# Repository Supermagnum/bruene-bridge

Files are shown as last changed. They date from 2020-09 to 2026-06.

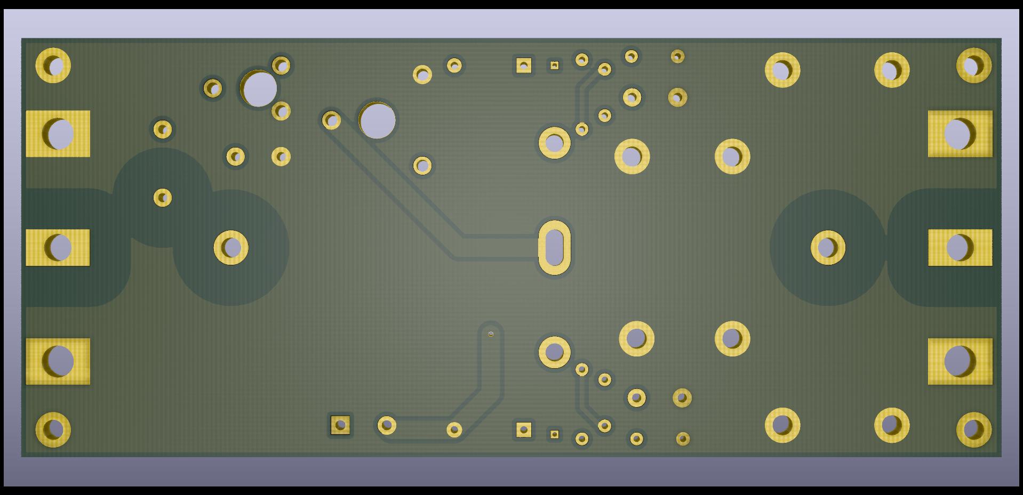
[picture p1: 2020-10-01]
SWR bridge-rendering-backside.jpg

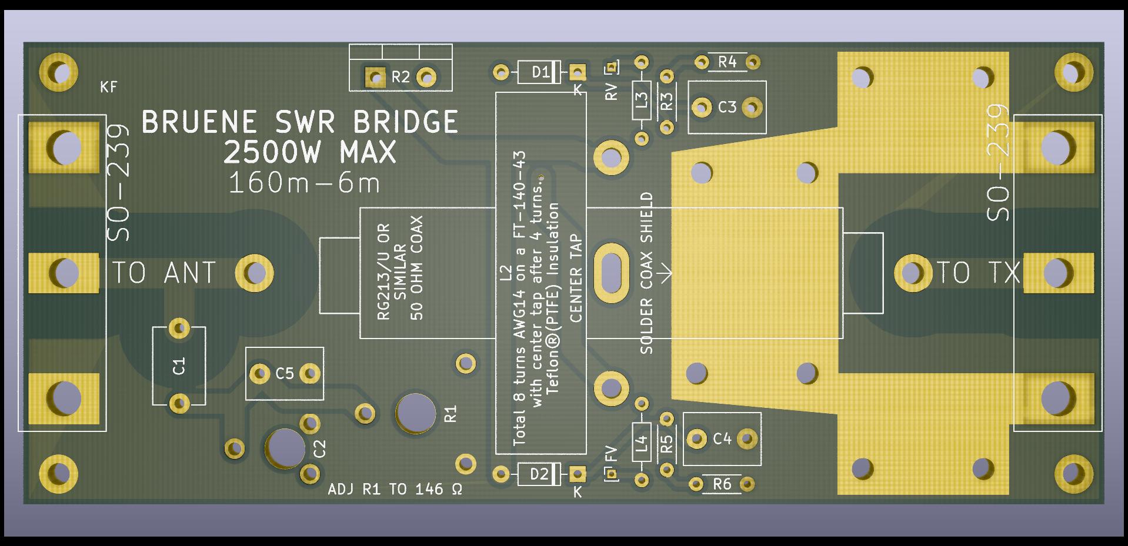
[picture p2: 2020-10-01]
SWR bridge-rendering.jpg

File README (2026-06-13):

SWR AND POWER MODIFIED BRUENE BRIDGE.

Circuit originally designed by F1FRV . 
This design is applicable for small or high powers, from 100 kHz (or less) to 50 Mhz, from miliwatts to kilowatts, depending on the selected components. For best results, for WIDEBAND use the ferrite "43" material. Materials "4C6 or 4C65" generaly painted in purple, are identical to material "61" and can also be used (with much more turns than "43" for same inductance).

With good electrical and mechanical design, using parts described here, and PCB designed for, 1.8 to 30 (50) MHz directivity can be better than 35 dB, and accuracy in power measurements in the range 1 to 2 %. 

Generaly, if it dont works, it is with people more clever, and better technicians than me, who dont want to follow EXACTLY what is written, and do what they feel instead.

Coaxial line shield must be grounded ONLY 1 side of toroid, 1 time at input connector, and 1 time just near toroid. Place the WIDE ground return strip(s), not a single wire, between coaxial line, circuit board and main ground frame, as close as possible to the toroid, to have the best accuracy in POWER measurements over a wide range of frequencies. For SWR measurements ONLY, this is not very important, as the ratio FWD/REF is independant of absolute values of detected voltages.To avoid parasitic capacitances, place the PCB at least 10 mm above metallic enclosures.

To have perfect balance of the bridge, with the calculated values given by EXCEL sheet, it is important to know the " TRUE " values of the coil(s), resistor R2, and capacitor C1. To know what is the exact Al value of your toroid, coil 5 turns of wire into it, measure with a LC meter, and divide value by 25. With an Ohmmeter, adjust VR1 to the value given by excel sheet.The variable C2 capacitor, as shown, is MANDATORY, to compensate for all tolerances in components values, parasitics. During tests, dont hesitate to modify calculated value of C2 (fixed + adjustable value) to obtain the best balance.Tolerances and parasitic capacitances management are unfortunately not exact sciences. Adjustment of phase compensation C2 must be made, ONLY at bridge maximum frequency of use. If null is not OK with C2, readjust slightly VR1 and C2, at max frequency of use, to obtain perfect null. Reverse bridge in /out to check null symetry.

Check of coil(s) and capacitor C1 exact values can be made with a LC meter, like the one described in pages " Technical " and proposed by DF1SR (ex DD0SB).

Adapt cross sectional area of wires in toroid to maximum current in R2, do not undersize, 3 Amps by square milimeter is a maximum.

Load on detector diodes is a first order parametre for rectified voltages output. Do not hesitate to use operational amplifiers LM358 or LM324 as buffers (they include GND in common mode range). In this case, with very high impedance detectors load, to avoid too high time constant in SWR readings, reduce, if necessary, the values of decoupling capacitors (ceramic) in FWD & REF outputs. 2.2 to 10 nF is OK with operational amplifiers, 100 nF or more without operational amplifiers.

Source for text : F1FRV 's page :
http://f1frv.free.fr/main3h_SWR_Bridges.html

What I have done:
Made a PCB that uses more modern components , as a example is C2 variable cap.
That one is impossible to use for a PCB design because the factory drawings is completely unreadable!
So, I have made adjustments with a smaller adjustable one that goes from 5.5-65pF in paralell with a 100 pF one. So the range of adjustment is 105 to 165 pF.

C1 is a 1pF ±0.5pF 4000V (4kV) Ceramic disc capacitator, clouse enough to the calulated 0,96 pF

I have added solder connectors to SO-239 connectors, 
they will fit if they are soldered in a 45 degree angle as then two of the mounting screws and the center pin can be soldered directly to the board.
It includes voltage dividers so the rectified forward and reverse voltages is suitable for a Aurdinos ADC ports ( 5v DC max ). 
The traces that carries RF is 3mm wide, and short.
It also includes a big area for soldering the coax cable shield to, 
and a copper strap can also be used to squeeze the coax cable shield between the strap and PCB.
It is also possible to mount grounding straps to the PCB. 

R2 is a 30W Through Hole Resistor TO-220-2, in a suitable location for mounting to the sheilded box wall or a heat sink. 

The PFD file contains calculations for up to 2500 W, more than enough because the legal limit in many places is 1000 W.
https://github.com/Supermagnum/bruene-bridge/blob/master/SWR-bridge.pdf

All components is THT.

PCB's:
https://aisler.net/p/KSGINYGY

PCB picture:
https://github.com/Supermagnum/bruene-bridge/blob/master/SWR%20bridge-rendering.jpg

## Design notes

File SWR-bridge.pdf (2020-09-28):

Revision 2 02/07/2004
Included in rectified voltage calculations the fact that:
Diode detection law below threshold voltage is linear
Diode detection law over threshold voltage is quadratic
Minimum detected power is taken as 0,5% of meter full scale
L1/R2 ratio at minimum frequecy decreased from >8 to ~5 to improve accuracy at high side of the useful band

Revision 3 17/07/2004
Included software MINIRK.EXE in spreadsheet Improved DC rectified voltages calculations lines 25 & 26

Revision 4 25/07/2004
Added wattmeter full scale value
Modified minimum detected power calculation

Revision 5 January 2006
Added schottky diode max voltage
and check of value in fwd & ref voltages. Becomes black on red if value too high

Revision 6 July 15, 2006
Check of value of diode maximum reverse peak voltage (Vr). Becomes black on red if value too low Diode Vr max shall be less than Vrms x ~4
Removed check in fwd & ref dc voltages

Revision 6a July 17, 2006
Added test measurements results table & graph Page now in "landscape"
Added calculations for R1 with 2 paralleded resistors

Revision 7a November 11, 2006
Added information about GND strap

Revision 7b April 21, 2007
Added Check flux with MINIRK12 to avoid toroid saturation at lowest frequency If toroid is saturated, increase size or redduce voltage

Revision 8 September 09, 2008
Modified bridge drawing to have phase compensation antenna side Added maximum flux in toroid verification sheet
Added selection list for toroids and automatic Al choice
Added AMIDON material 43 and 61 toroids data

Revision 8a September 10, 2008
Added material "2" in calculations and documentation

Revision 8b September 19, 2008
Included coupling factor 99% for L1
added nota about ratio L1/R2 and accuracy

Revision 8c September 30, 2008
added warning colors for ratio L1/R2 less than 7 and 5

Revision 8d November 06, 2008
Modified safety ratio warning for detectors PIV. Is now 2.88 x RMS voltage

Revision 8e November 23, 2010
Correction of not very clear texts: in C1 manual calculation
and in R2 dissipated power

Revision 9 November 25, 2010
Added TRUE MEASURED value of toroid AL

Revision 10 December 07, 2010
Added minimum supply voltage of automatic SWR board

Revision 10a March 30, 2011
Added nota about TRUE measured AL

Revision 10b April 21, 2011
Corrected data source in results graph which was not working

Revision 10c February 1st, 2012
Added nota line 30, to decrease output voltages if necessary.

Revision 10d August 15, 2012

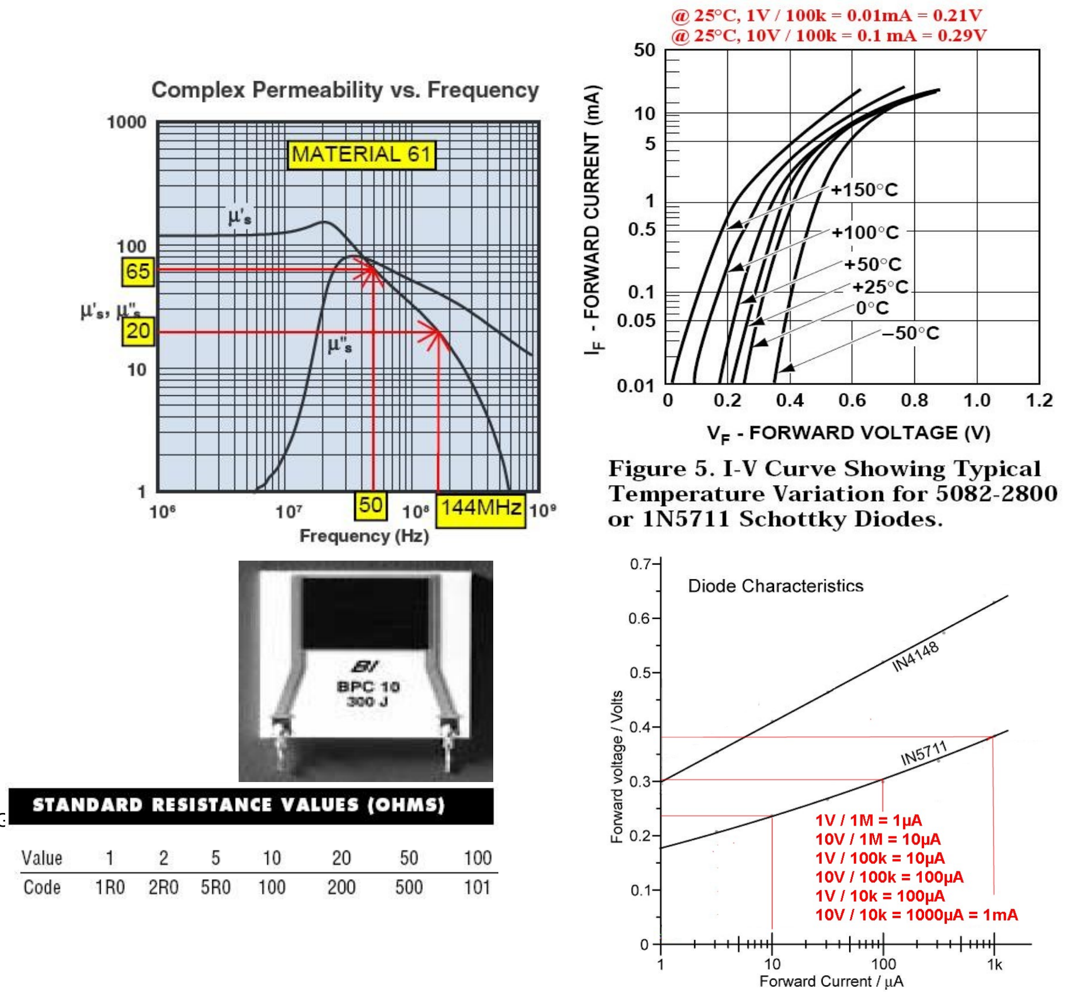
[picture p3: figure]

Deleted the material 2, red toroids, as NOT ADAPTED TO WIDEBAND DESIGNS

Revision 11 January 07, 2014
Modified Cell C18: C2 (pF) adjustable (+ fixed value if necessary)
Formula was: =(2*2^0.5*C8*C16*C3)/C12-C16
Formula now: =(2*C8*C16*C3)/C12-C16
Replaced R1 by variable resistor VR1

NOTA: For monoband 50 MHz with material 61, divide NOMINAL Al of toroid by 2 NOTA: For monoband 144 MHz with material 61, divide NOMINAL Al of toroid by 6

Revision 12 December 11, 2014
Modified Cell C7: Becomes "True AL" if true AL entered in cell F7
Added nota about max nb of turns.
R2 BPC10 (10 Watts) serie standard values see picture
Added wire CSA calculation
Added notas lines 31 to 33

Revision 13 January 2020
Modified formula in cells C26 & C27 which was: =SI(C20>C25;((C25+(C20-C25)*PI()/2));C20)

F1FRV January 2020 REVISION 13 | MEASUREMENT RESULTS WITH POWER 40 WATTS / 50 OHMS WITH
VOLTMETER 10 MEGOHMS/V
LINE IMPEDANCE Z (Ohms) | 50 | | | | FREQUENCY (MHz) | FWD VALUE | | REF VALUE
Maximum power (Watts) | | | | | 1,8 | 690 | mV | 0,10 | mV | FT 50-43
| 10,0 | | | | 3,5 | 693 | mV | 0,10 | mV | FT 82-43
Reference of toroid | FT 140-43 | >> | | | 5,0 | 694 | mV | 0,10 | mV | FT 114-43
| 885,0 | >> | | | 7,0 | 695 | mV | 0,10 | mV | FT 140-43
| 8 | | | | 10,0 | 689 | mV | 0,10 | mV | FT 240-43
L1 (uH) with coupling factor 0.99 | 56,074 | If Total Nb of turns > 10, Decrease R2 value. | 14,0 | 680 | mV | 0,10 | mV | FT 50-61
Bridge Minimum Frequency of use (MHz) | 1,800 | This, to minimize L1 parasitic capacitances. | 18,0 | 678 | mV | 0,10 | mV | FT 82-61
126,8 | >> L1/R2 = 3 power error ~5% and phase ~18° | 21,0 | 679 | mV | 0,10 | mV | FT 114-61
R2 (Ohms) Shall be NON INDUCTIVE !!! | 5,00 | L1/R2 = 7 power error ~1% and phase ~8° | 24,9 | 680 | mV | 0,10 | mV | FT 140-61
Max current in R2 and toroid winding (Amps) | 3,95 | >> Wire MIN CSA (sq mm) | 1,32 | 28,0 | 689 | mV | 0,10 | mV | FT 240-61
Bridge coupling design dB | 47,09 | | Wire MIN Dia. (mm) | 1,30 | 30,0 | 682 | mV | 0,10 | mV | ??
R2 dissipated power (Watts) at maximum permanent power | 7,81 | >> | AT MAXIMUM SWR : | 10,00 | 50,0 | 683 | mV | 0,10 | mV | ??
C1 (pF) | 0,96 | >> | 2 x RG 402 | pF/m | MEAN VALUE | 686 | mV | 0,10 | mV | ??
Max Voltage on C1 (Volts peak/peak) | | | 2 x 2000 V MAX | 95,1 | MAXIMUM ERROR +/- | 1,8 | % | | | ??
C2 (pF) adjustable (+ C2a fixed value if necessary) | 152,6 | C1 MANUAL CALCULATION | BRIDGE DIRECTIVITY | 38,4 | dB | ??
VR1 variable resistor to adjust with Ohmmeter at value | | | 2 lengths of (mm) | 20,0
FWD Volts on R2 (Volts rms) | 5,44 | | C1 (pF) incl. strays | 0,96
REF Voltage on R2 (Volts rms) | 4,45 | See Picture at page bottom
FWD Apparent Power (Watts)
REF Apparent Power (Watts)
Detection diode maximum Peak Inverse Voltage (Volts) | 70 | >> | See diode manufacturer data for values.
Detection diode Treshold Forward Voltage (Volts) | 0,180 | >> | Quadratic detection below threshold voltage
Estimated forward rectified voltage (DC Volts) | 7,611 | Linear detection over threshold voltage (FV).
Estimated reflected rectified voltage (DC Volts) | 6,213
With output power (Watts) | | | Auto SWR supply V > 9,7
Minimum reflected detected power will be (Watts) | 0,364 | >> with directivity measured in tests
Nota: If necessary, install a resistive divider to reduce FWD & REF voltages outputs, for auto SWR lower supply voltage. To estimate maximum output voltages & currents, modify max SWR (cell B5)
IMPORTANT: C2 adjustment mus be made ONLY at bridge maximum frequency of service.

COLOR CODE: INPUTS= BLUE / OUTPUTS= RED / INFORMATION= BLACK
( See revisions page ) | ENTER YOUR MEASURED VALUES !!

2 500
PERMANENT Maximum SWR to be accepted by the bridge CLICK HERE FOR TOROID FLUX VERIFICATION PAGE !! Nominal average AL of toroid (nH / turn²
) | True measured AL :
Nb TOTAL of turns (N) INSIDE toroid (2 x N/2) ( MUST be EVEN !! ) | True measured AL MUST stay BLANK if no measured AL

L1 / R2 ratio at minimum freq. (shall be >7 for <1% accuracy )

1 581

146 025

7 562,50
5 062,50 | 1N4148 (PIV 100V, FV 0.3V @ 1uA) High FV.

1N5711 (PIV 70V, FV 0.18V @ 1uA) is the best. 2 500

Nota: Coaxial line must be grounded ONLY 1 SIDE OF TOROID, 1 x just behind toroid, AND 1 x at TX connector.

1,8
3,5

5,0

7,0
10,0
14,0

18,0

21,0

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
1000

### FWD DETECTION (mV) @ FREQUENCY (MHz)

TOROIDS FLUX CALCULATIONS | CALCUL DU FLUX DANS LES TORES | F1FRV January 2020 REVISION 13
Results: Red on yellow | Résultats: Rouge sur fond jaune

IF FLUX IS TOO HIGH, INCREASE NB OF SECONDARY TURNS !!!!
SI LE FLUX EST TROP IMPORTANT, AUGMENTER LE NB DE SPIRES SECONDAIRE !!!!
Toroids | Tores | FT 50-43 | FT 82-43 FT 114-43 FT 140-43 FT 240-43
1 toroid nominal specific inductance (Al) | Inductance specifique nominale (Al) d'un tore | 480 | 470 | 510 | 885 | 1075 | nH/Sp2
1 toroid Cross sectional area | Section d'un tore | 0,133 | 0,246 | 0,375 | 0,806 | 1,61 | Cm2
Maximum flux density for material 43 | Flux maximum pour Materiau 43 | 2750 | 2750 | 2750 | 2750 | 2750 | Gauss
Max flux to be used (20% of max flux) | Flux à ne pas depasser (20% du flux maxi) | 550 | 550 | 550 | 550 | 550 | Gaus
Flux density | Flux | 520 | 281 | 184 | 86 | 43 | Gauss
Toroids | Tores | FT 50-61 | FT 82-61 FT 114-61 FT 140-61 FT 240-61
1 toroid nominal specific inductance (Al) | Inductance specifique nominale (Al) d'un tore | 69 | 75 | 80 | 140 | 170 | nH/Sp2
1 toroid Cross sectional area | Section | 0,133 | 0,246 | 0,375 | 0,806 | 1,61 | Cm2
Maximum flux density for material 61 | Flux maximum pour Materiau 61 | 2350 | 2350 | 2350 | 2350 | 2350 | Gauss
Max flux to be used (20% of max flux) | Flux à ne pas depasser (20% du flux maxi) | 470 | 470 | 470 | 470 | 470 | Gaus
Flux density | Flux | 520 | 281 | 184 | 86 | 43 | Gauss

SWR Calculations by Ron Barker, G4JNH
Enter Zo | 50,0 | 50,0 | 50,0 | 50,0 | 50,0 ohms
Enter delivered power at wattmeter | 2500,0 | 2500,0 | 2500,0 | 2500,0 | 2500,0 watts
Enter SWR | 10,00 | 10,00 | 10,00 | 10,00 | 10,00
Angle of reflection coefficient at wattmeter | 0,0 | 45,0 | 90,0 | 135,0 | 180,0 degrees
Magnitude of reflection coefficient is | 0,818 | 0,818 | 0,818 | 0,818 | 0,818
Forward voltage is | 614,9 | 614,9 | 614,9 | 614,9 | 614,9 volts (rms)
Forward current is | 12,298 | 12,298 | 12,298 | 12,298 | 12,298 amps (rms)
Forward power is | 7562,5 | 7562,5 | 7562,5 | 7562,5 | 7562,5 watts
Reflected voltage is | 503,1 | 503,1 | 503,1 | 503,1 | 503,1 volts (rms)
Reflected current is | 10,062 | 10,062 | 10,062 | 10,062 | 10,062 amps (rms)
Reflected power is | 5062,5 | 5062,5 | 5062,5 | 5062,5 | 5062,5 watts
Line voltage at Wattmeter is | 1118,0 | 1033,8 | 794,5 | 440,1 | 111,8 volts (rms)
Phase angle referenced to forward voltage is | 0,000 | 0,351 | 0,686 | 0,941 | 0,000 radians
Percentage of reflected power | 66,94215 66,94215 66,94215 66,94215 66,94215 %
Percentage of reflected voltage | 81,81818 81,81818 81,81818 81,81818 81,81818 %
Line current at wattmeter is | 2,236 | 8,803 | 15,890 | 20,676 | 22,361 amps (rms)
Phase angle referenced to forward current is | 0,000 | -0,941 | -0,686 | -0,351 | 0,000 radians
Coupling dB | 47,0927 | 47,0927 | 47,0927 | 47,0927 | 47,0927 dB
Coupling ratio | 226,2742 226,2742 226,2742 226,2742 226,2742
Voltage derived from voltage sampler (Ev) is | 4,941 | 4,569 | 3,511 | 1,945 | 0,494 volts (rms)
Voltage derived from current sampler (Ei) is | 0,494 | 1,945 | 3,511 | 4,569 | 4,941 volts (rms)
Phase angle between Ev and Ei is | 0,000 | -1,293 | -1,371 | -1,293 | 0,000 radians
Vector sum of Ev and Ei is | 5,435 | 5,435 | 5,435 | 5,435 | 5,435 volts (rms)
Vector difference between Ev and Ei is | 4,447 | 4,447 | 4,447 | 4,447 | 4,447 volts (rms)
Rectified voltage presented to forward power meter is | 7,686 | 7,686 | 7,686 | 7,686 | 7,686 volts DC
Rectified voltage presented to reflected power meter is | 6,289 | 6,289 | 6,289 | 6,289 | 6,289 volts DC
Derived magnitude of reflection coefficient is | 0,818 | 0,818 | 0,818 | 0,818 | 0,818
Derived SWR is | 10,00 | 10,00 | 10,00 | 10,00 | 10,00
Ev/Ei ratio | 10,00 | 2,35 | 1,00 | 0,43 | 0,10

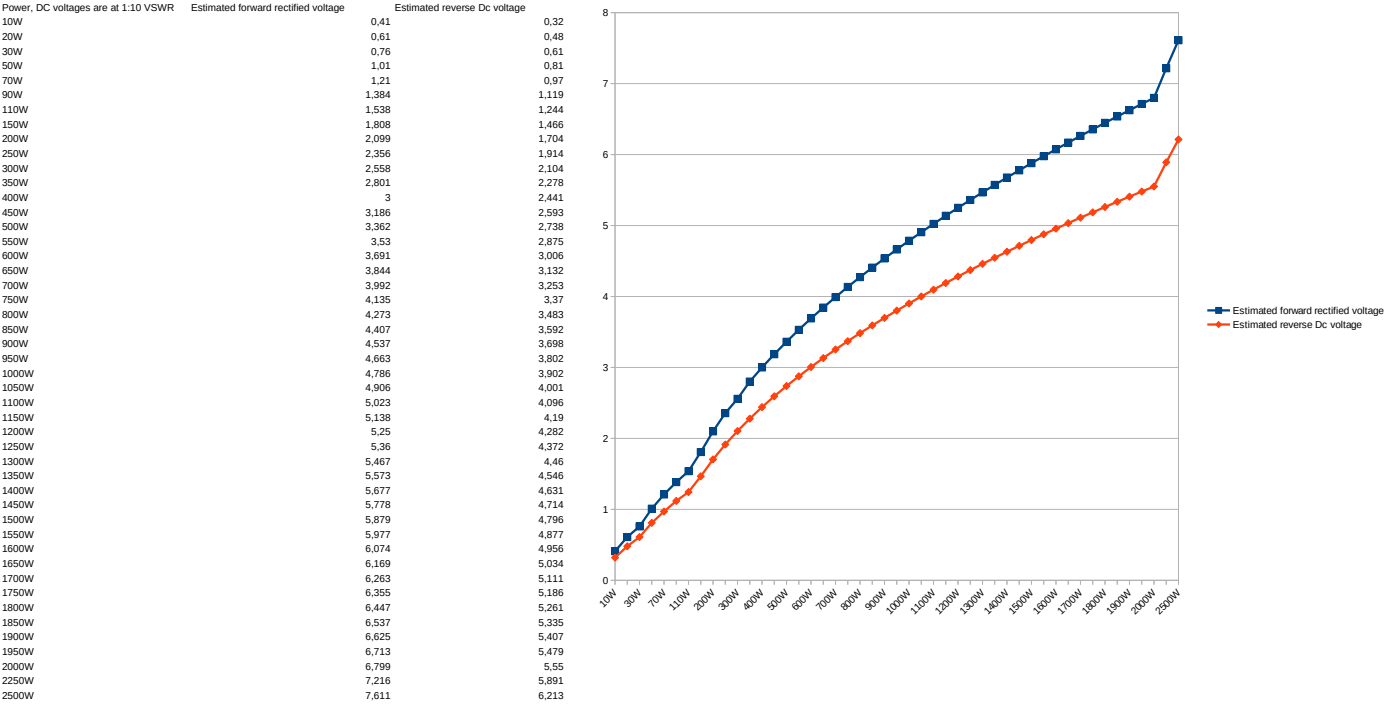
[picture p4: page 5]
Power, DC voltages are at 1:10 VSWR; Estimated forward rectified voltage; Estimated reverse Dc voltage

Estimated forward rectified voltage
Estimated reverse Dc voltage

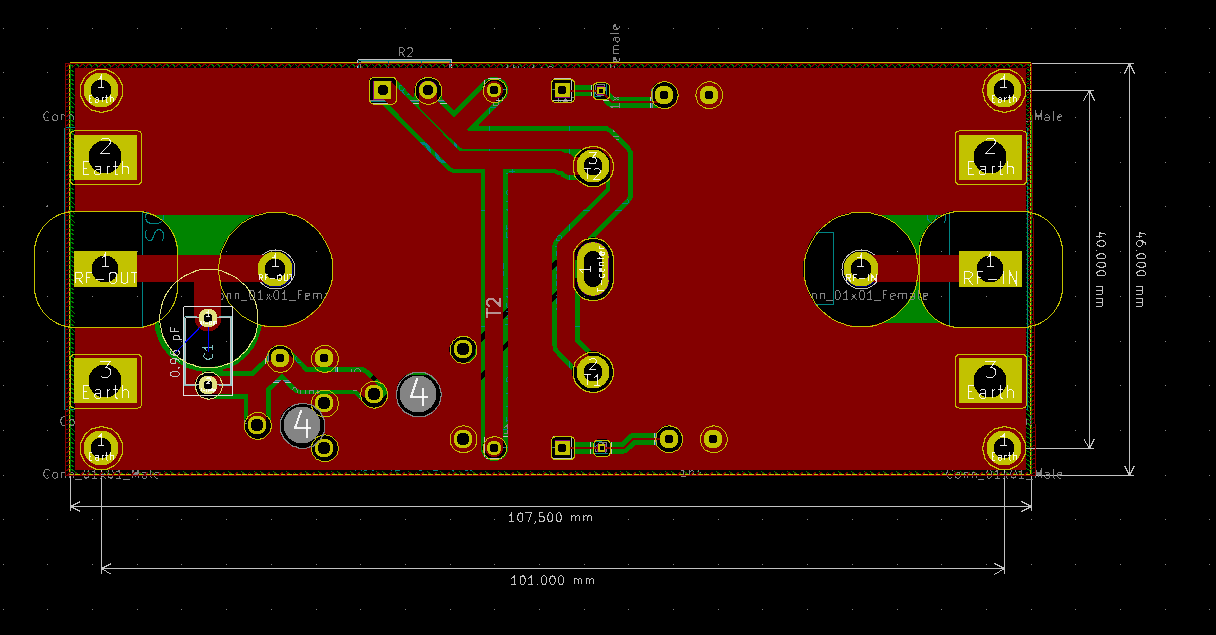
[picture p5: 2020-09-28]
dimentions-pcb.png

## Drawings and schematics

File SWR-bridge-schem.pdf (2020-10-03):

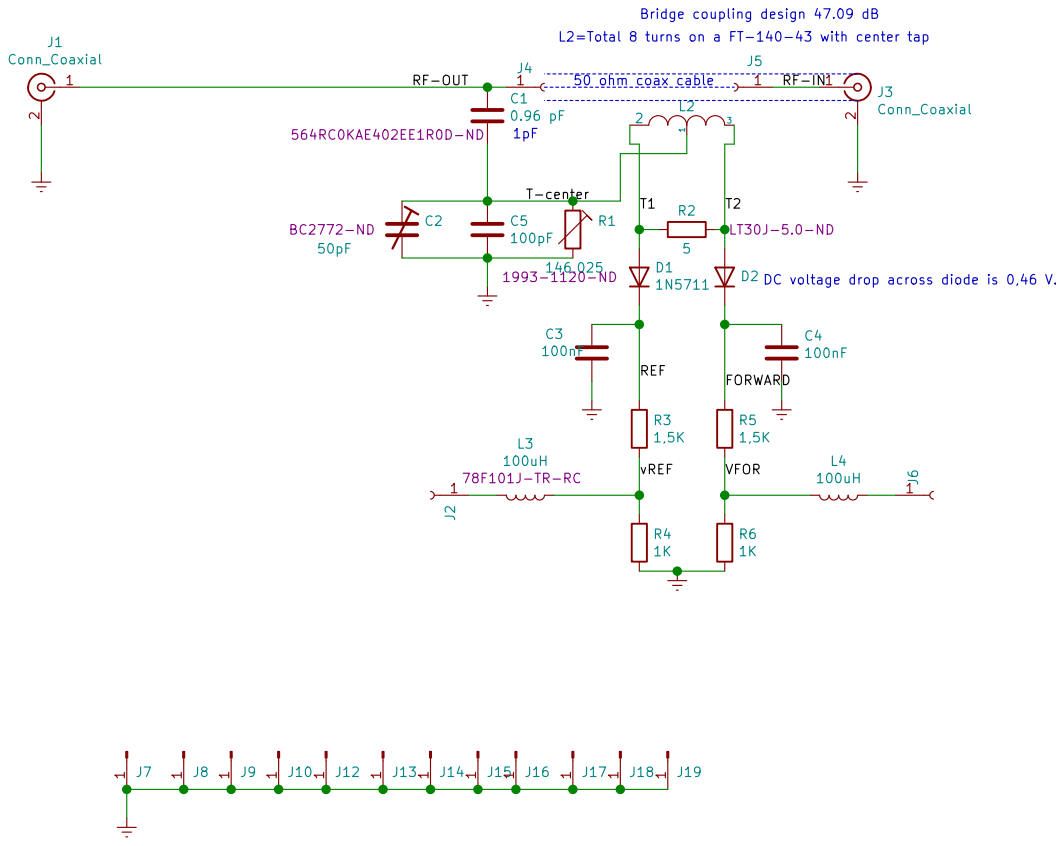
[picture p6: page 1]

50 ohm coax cable Bridge coupling design 47.09 dB
L2=Total 8 turns on a FT-140-43 with center tap

DC voltage drop across diode is 0,46 V.

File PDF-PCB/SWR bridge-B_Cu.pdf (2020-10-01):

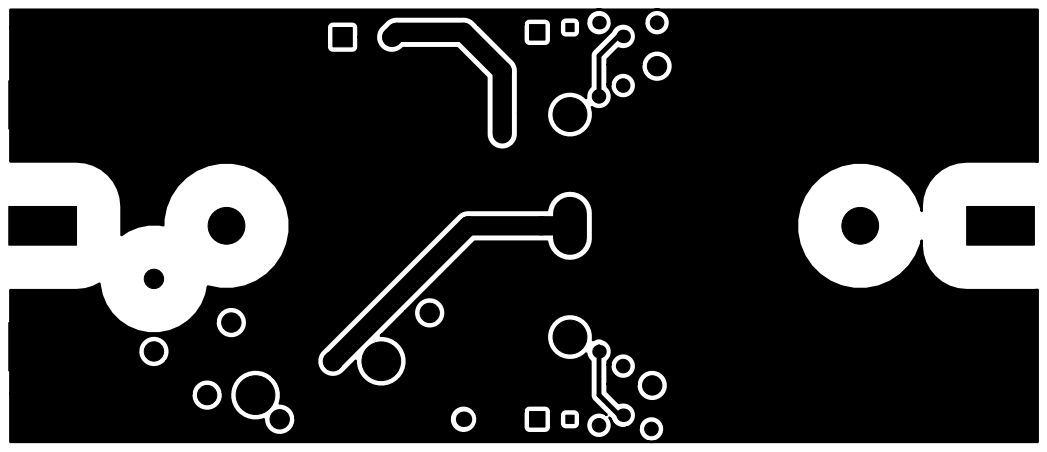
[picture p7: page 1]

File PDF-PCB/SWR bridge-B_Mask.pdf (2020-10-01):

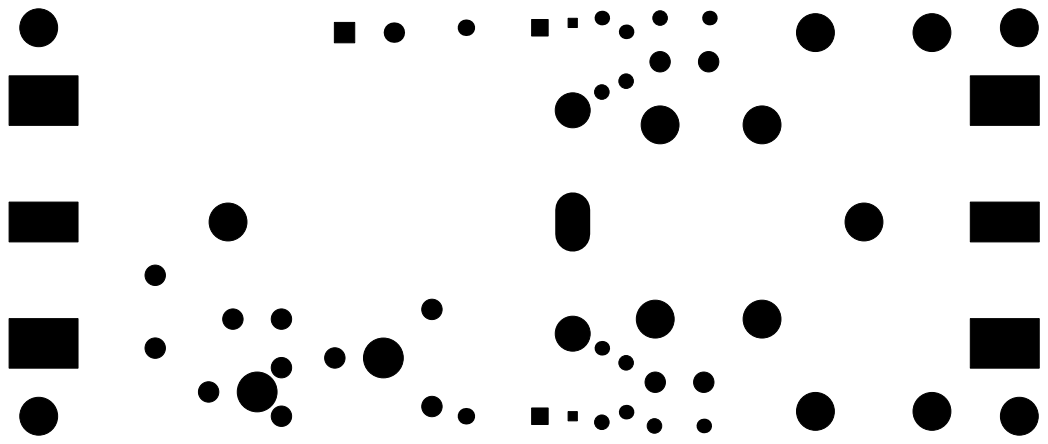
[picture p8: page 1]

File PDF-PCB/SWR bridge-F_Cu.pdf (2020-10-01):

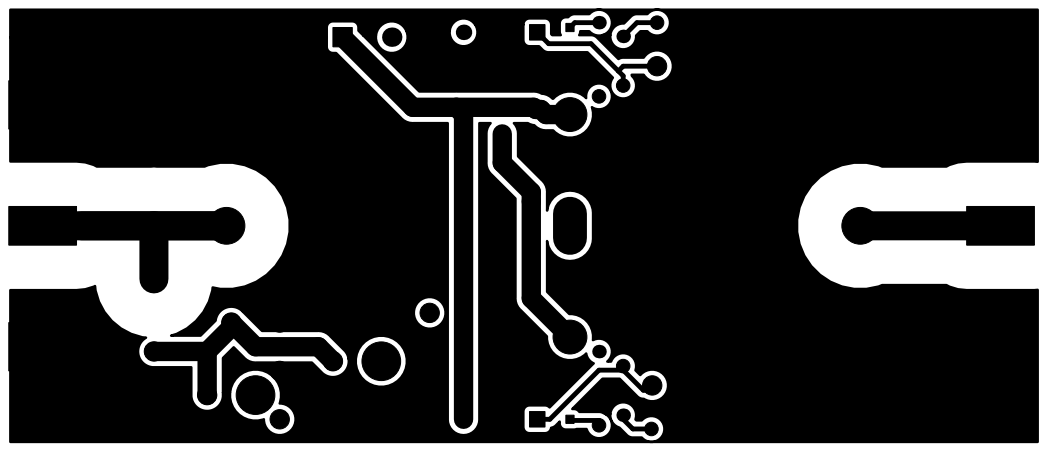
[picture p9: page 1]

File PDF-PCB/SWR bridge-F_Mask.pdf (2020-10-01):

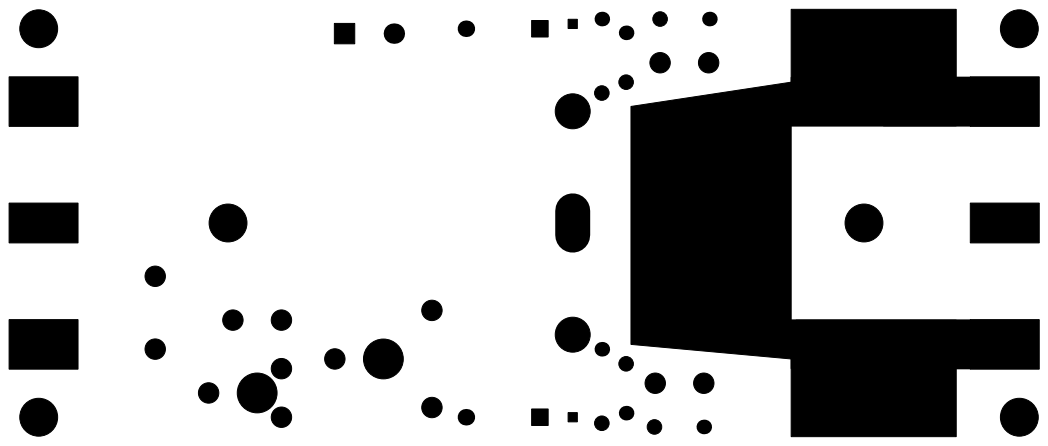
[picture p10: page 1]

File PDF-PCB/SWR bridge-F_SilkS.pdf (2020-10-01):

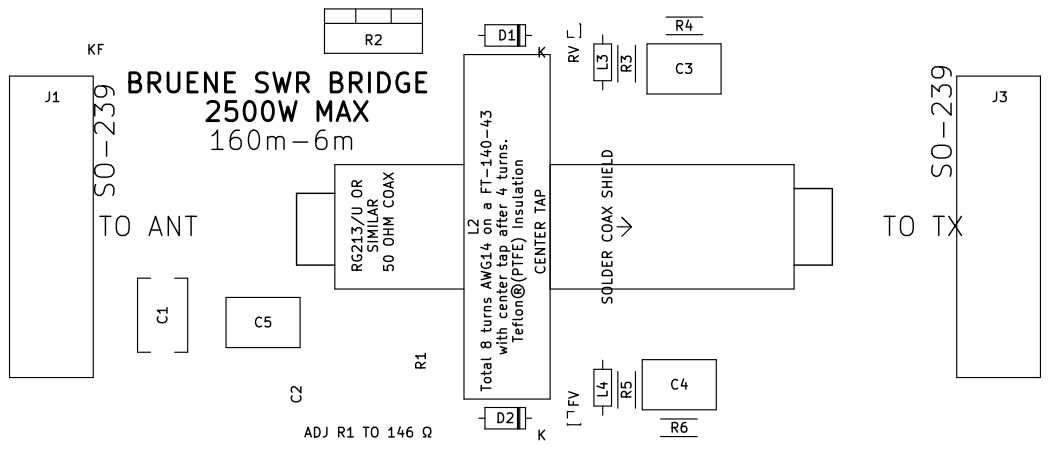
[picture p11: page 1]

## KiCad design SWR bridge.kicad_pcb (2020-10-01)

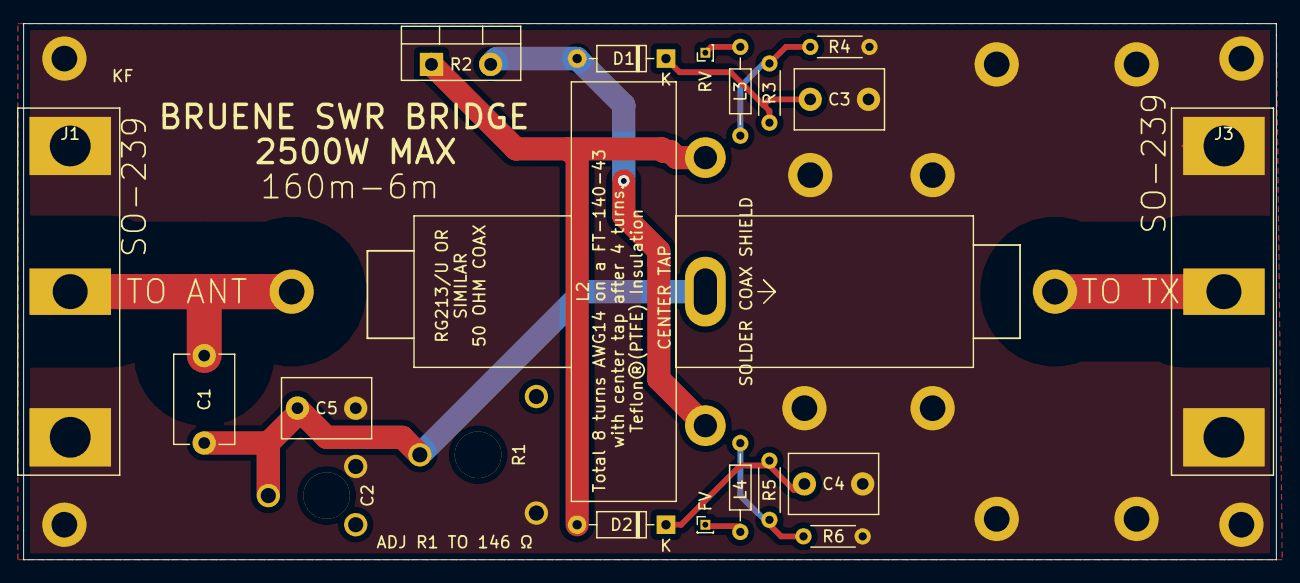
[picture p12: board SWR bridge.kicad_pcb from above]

Board: 2 copper layers, 107.5 x 46.0 mm, 34 parts (0 on the bottom side), 12 nets.

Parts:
C1: 0.96 pF; C_Disc_D7.5mm_W5.0mm_P7.50mm
C2: 50pF; BC2772-ND
C3, C4: 1nF; C_Disc_D7.5mm_W5.0mm_P5.00mm
C5: 100pF; C_Disc_D7.5mm_W5.0mm_P5.00mm
D1: 1N5711; D_DO-35_SOD27_P7.62mm_Horizontal
D2: 1N4148; D_DO-35_SOD27_P7.62mm_Horizontal
J1, J3: Conn_Coaxial; SO-239-V
J2, J6: Conn_01x01_Female; PinHeader_1x01_P1.00mm_Vertical
J4, J5: Conn_01x01_Female; MountingHole_2.2mm_M2_DIN965_Pad
J7, J8, J9, J10, J12, J13, J14, J15, J16, J17, J18, J19: Conn_01x01_Male; MountingHole_2.2mm_M2_DIN965_Pad
L2: INDUCTOR-TAP
L3, L4: 100uH; R_Axial_DIN0204_L3.6mm_D1.6mm_P7.62mm_Horizontal
R1: 146,025; PT10LV10
R2: 5; TO-220-2_Vertical
R3, R5: 1,5K; R_Axial_DIN0204_L3.6mm_D1.6mm_P5.08mm_Horizontal
R4, R6: 1K; R_Axial_DIN0204_L3.6mm_D1.6mm_P5.08mm_Horizontal

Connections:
/FORWARD: C4.1, D2.1, R5.1
/REF: C3.1, D1.1, R3.1
/RF-IN: J3.1, J5.1
/RF-OUT: C1.1, J1.1, J4.1
/T1: D1.2, L2.2, R2.2
/T2: D2.2, L2.3, R2.1
/T-center: C1.2, C2.1, C5.1, L2.1, R1.1
/VFOR: L4.2, R5.2, R6.1
/vREF: L3.1, R3.2, R4.1
Earth: C2.2, C3.2, C4.2, C5.2, J1.2, J1.3, J3.2, J3.3, J7.1, J8.1, J9.1, J10.1, J12.1, J13.1, J14.1, J15.1, J16.1, J17.1, J18.1, J19.1, R1.2, R4.2, R6.2
unnamed: J2.1, L3.2
unnamed: J6.1, L4.1

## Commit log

2020-09-28 Add files via upload
    added some files.
    [SWR bridge.kicad_pcb, SWR-bridge.ods, SWR-bridge.xlsx]
2020-09-28 Add files via upload
    Added gerber files and pdf files for PCB fabrication.
    [SWR bridge-B_Cu.gbr, SWR bridge-B_Mask.gbr, SWR bridge-B_Paste.gbr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]
2020-09-30 Add files via upload
    Updated gerber files
    [SWR bridge-B_Cu.gbr, SWR bridge-B_Mask.gbr, SWR bridge-B_Paste.gbr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]
2020-09-30 Add files via upload
    updated pdf files
    [SWR bridge-NPTH.drl, SWR bridge-PTH.drl]
2020-09-30 Add files via upload
    added mounting holes for ground straps.
    [SWR bridge-B_Cu.gbr, SWR bridge-B_Mask.gbr, SWR bridge-B_Paste.gbr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]
2020-09-30 Add files via upload
    updated pfd files with holes for mounting ground straps.
    [SWR bridge-NPTH.drl, SWR bridge-PTH.drl]
2020-10-01 Add files via upload
    updated files
    [SWR bridge.kicad_pcb]
2020-10-01 Add files via upload
    updated gerbers
    [SWR bridge-B_Cu.gbr, SWR bridge-B_Mask.gbr, SWR bridge-B_Paste.gbr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]
2020-10-01 Add files via upload
    updated pdf files for fabrication
    [SWR bridge-NPTH.drl, SWR bridge-PTH.drl]
2020-10-01 Add files via upload
    update
    [SWR bridge.kicad_pcb]
2020-10-01 Add files via upload
    updated
    [SWR bridge-NPTH.drl, SWR bridge-PTH.drl]
2020-10-01 Add files via upload
    Changed C4 and C3 to 40 nF , to minimize ripple on the rectified voltages.
2026-06-13 Update README to reflect changes in PCB design
    Removed outdated Dropbox link and clarified PCB design improvements.
